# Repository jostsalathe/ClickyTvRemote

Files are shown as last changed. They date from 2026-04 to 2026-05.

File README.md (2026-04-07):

# ClickyTvRemote
A custom IR TV remote with mechanical keyboard switches

The project started because we have no remote any more for our Philips 32PFL5403D/12 TV.

IR codes for this Model can be found in the [IRDB on Github](https://github.com/probonopd/irdb/blob/master/codes/Philips/Unknown_32PFL5403D/0%2C-1.csv).

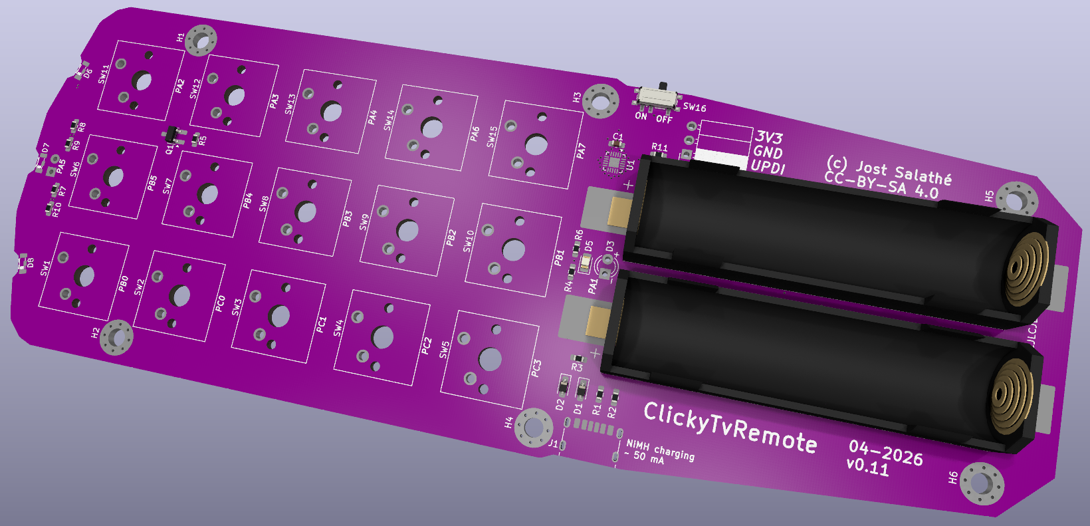
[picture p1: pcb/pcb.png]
PCB image


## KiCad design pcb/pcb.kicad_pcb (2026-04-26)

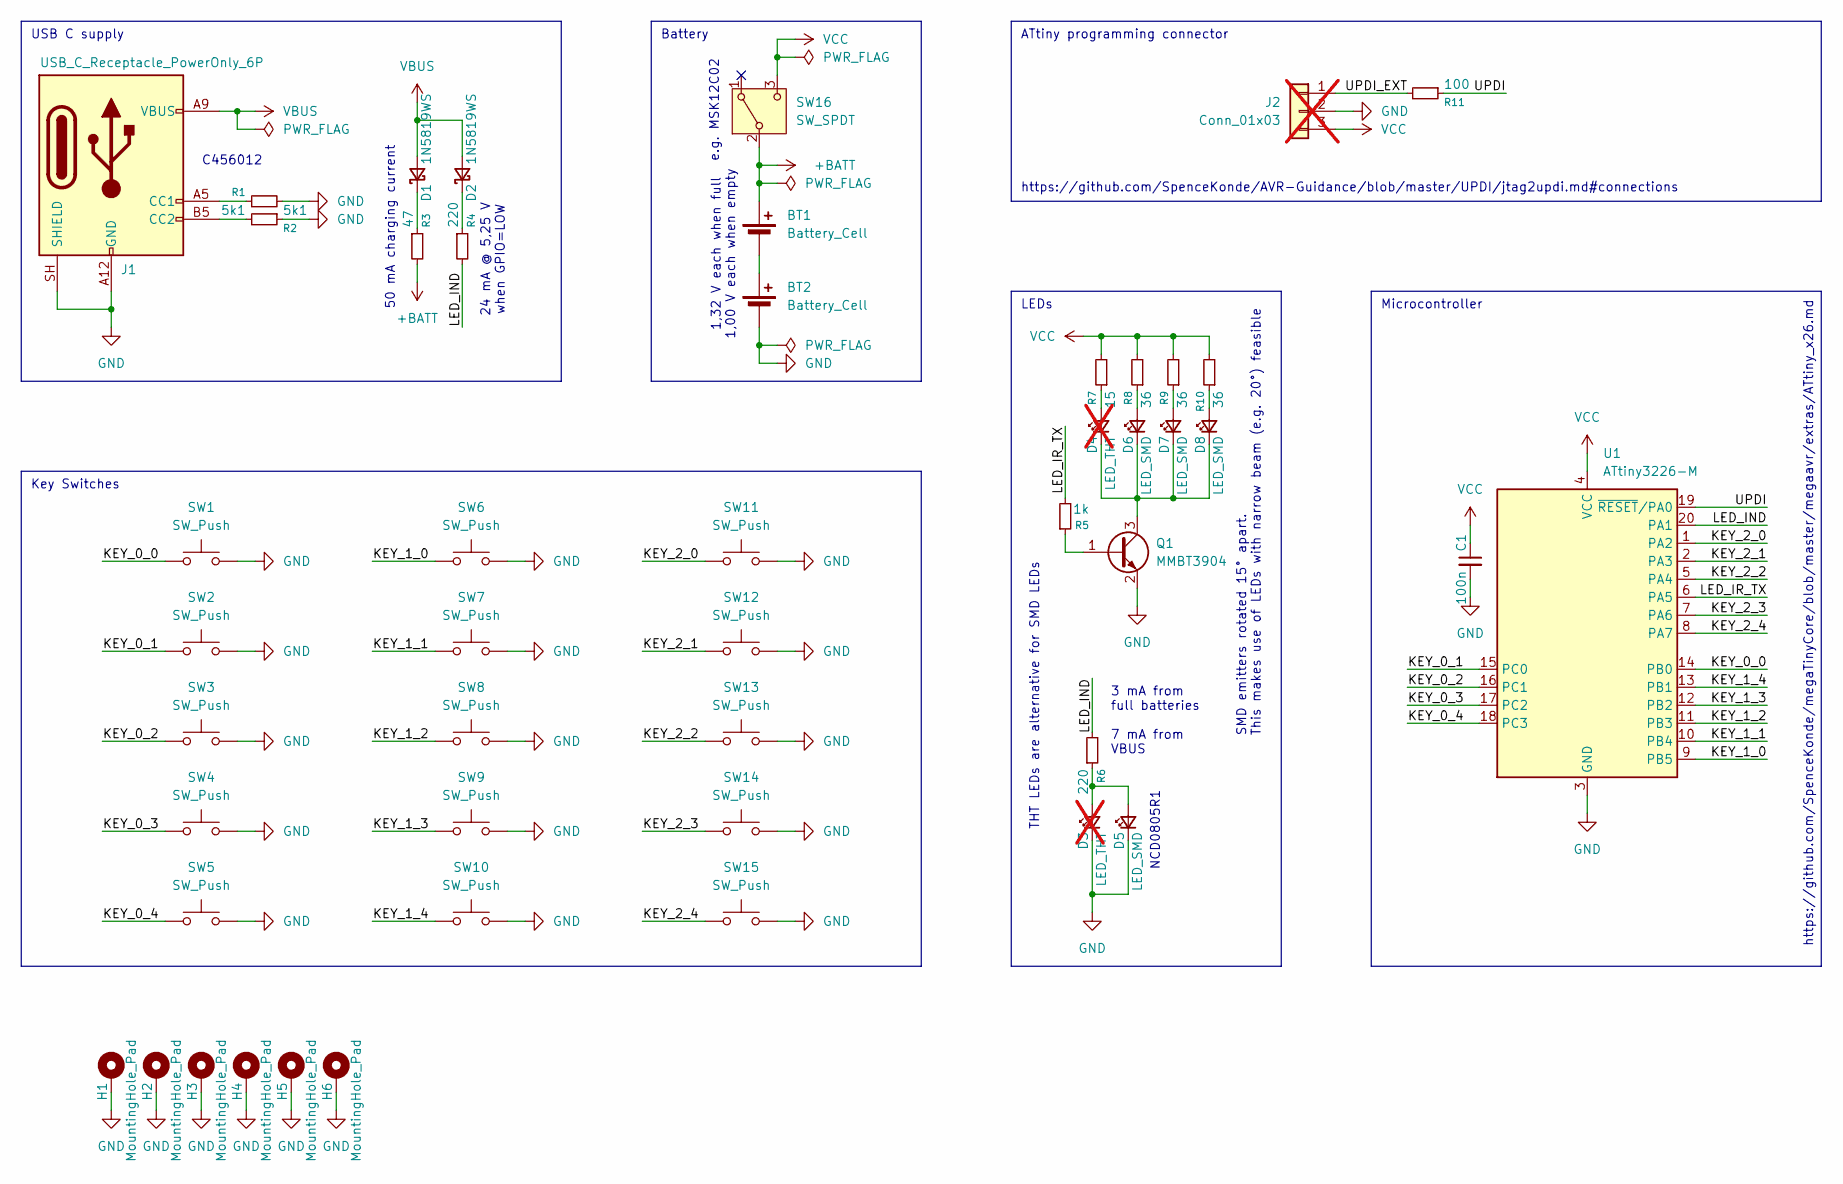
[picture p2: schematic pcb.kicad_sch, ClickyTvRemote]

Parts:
BT1, BT2: Battery_Cell; MYOUNG_AA_BH-AA-B5BA026; LCSC C20606794
C1: 100n; C_0603_1608Metric_Pad1.08x0.95mm_HandSolder; LCSC C14663
D1, D2: 1N5819WS; D_SOD-323_HandSoldering; LCSC C191023
D3: LED_THT; LED_D3.0mm; not fitted
D4: LED_THT; LED_D3.0mm_Horizontal_O1.27mm_Z2.0mm_IRBlack; not fitted
D5: LED_SMD; LED_0805_2012Metric_Pad1.15x1.40mm_HandSolder; LCSC C84256
D6, D7, D8: LED_SMD; IR12-21CTR8; LCSC C53672
H1, H2, H3, H4, H5, H6: MountingHole_Pad; MountingHole_3.2mm_M3_Pad_Via
J1: USB_C_Receptacle_PowerOnly_6P; USB_C_Receptacle_HRO_TYPE-C-31-M-17; LCSC C456012
J2: Conn_01x03; PinSocket_1x03_P2.54mm_Horizontal; not fitted
Q1: MMBT3904; SOT-23_Handsoldering; LCSC C20526
R1, R2: 5k1; R_0603_1608Metric_Pad0.98x0.95mm_HandSolder; LCSC C23186
R3: 47; R_0603_1608Metric_Pad0.98x0.95mm_HandSolder; LCSC C23182
R4, R6: 220; R_0603_1608Metric_Pad0.98x0.95mm_HandSolder; LCSC C22962
R5: 1k; R_0603_1608Metric_Pad0.98x0.95mm_HandSolder; LCSC C21190
R7: 15; R_0603_1608Metric_Pad0.98x0.95mm_HandSolder; LCSC C22810
R8, R9, R10: 36; R_0603_1608Metric_Pad0.98x0.95mm_HandSolder; LCSC C23148
R11: 100; R_0603_1608Metric_Pad0.98x0.95mm_HandSolder; LCSC C22775
SW1, SW2, SW3, SW4, SW5, SW6, SW7, SW8, SW9, SW10, SW11, SW12, SW13, SW14, SW15: SW_Push; SW_Cherry_MX_1.00u_PCB
SW16: SW_SPDT; SW_SPDT_PCM12; LCSC C431540
U1: ATtiny3226-M; VQFN-20-1EP_3x3mm_P0.4mm_EP1.7x1.7mm; LCSC C5227682

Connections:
+BATT: BT1.1 (+), R3.2, SW16.2 (B)
/KEY_0_0: SW1.1, U1.14 (PB0)
/KEY_0_1: SW2.1, U1.15 (PC0)
/KEY_0_2: SW3.1, U1.16 (PC1)
/KEY_0_3: SW4.1, U1.17 (PC2)
/KEY_0_4: SW5.1, U1.18 (PC3)
/KEY_1_0: SW6.1, U1.9 (PB5)
/KEY_1_1: SW7.1, U1.10 (PB4)
/KEY_1_2: SW8.1, U1.11 (PB3)
/KEY_1_3: SW9.1, U1.12 (PB2)
/KEY_1_4: SW10.1, U1.13 (PB1)
/KEY_2_0: SW11.1, U1.1 (PA2)
/KEY_2_1: SW12.1, U1.2 (PA3)
/KEY_2_2: SW13.1, U1.5 (PA4)
/KEY_2_3: SW14.1, U1.7 (PA6)
/KEY_2_4: SW15.1, U1.8 (PA7)
/LED_IND: R4.2, R6.2, U1.20 (PA1)
/LED_IR_TX: R5.2, U1.6 (PA5)
/UPDI: R11.1, U1.19 (~RESET/PA0)
/UPDI_EXT: J2.1, R11.2
GND: BT2.2 (-), C1.2, D3.1 (K), D5.1 (K), H1.1 (1_1), H2.1 (1_1), H3.1 (1_1), H4.1 (1_1), H5.1 (1_1), H6.1 (1_1), J1.A12 (GND), J1.B12 (GND), J1.SH (SHIELD), J2.2, Q1.2 (E), R1.2, R2.1, SW1.2, SW2.2, SW3.2, SW4.2, SW5.2, SW6.2, SW7.2, SW8.2, SW9.2, SW10.2, SW11.2, SW12.2, SW13.2, SW14.2, SW15.2, U1.3 (GND), U1.21 (GND)
unnamed: BT1.2 (-), BT2.1 (+)
unnamed: D1.1 (K), R3.1
unnamed: D2.1 (K), R4.1
unnamed: D3.2 (A), D5.2 (A), R6.1
unnamed: D4.2 (A), R7.1
unnamed: D4.1 (K), D6.1 (K), D7.1 (K), D8.1 (K), Q1.3 (C)
unnamed: D6.2 (A), R8.1
unnamed: D7.2 (A), R9.1
unnamed: D8.2 (A), R10.1
unnamed: J1.A5 (CC1), R1.1
unnamed: J1.B5 (CC2), R2.2
unnamed: Q1.1 (B), R5.1
VBUS: D1.2 (A), D2.2 (A), J1.A9 (VBUS), J1.B9 (VBUS)
VCC: C1.1, J2.3, R7.2, R8.2, R9.2, R10.2, SW16.3 (C), U1.4 (VCC)

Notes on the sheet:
Microcontroller
THT LEDs are alternative for SMD LEDs
Key Switches
https://github.com/SpenceKonde/megaTinyCore/blob/master/megaavr/extras/ATtiny_x26.md
https://github.com/SpenceKonde/AVR-Guidance/blob/master/UPDI/jtag2updi.md#connections
24 mA @ 5,25 V when GPIO=LOW
3 mA from full batteries 7 mA from VBUS
1,32 V each when full 1,00 V each when empty
e.g. MSK12C02
C456012
NCD0805R1
Battery
LEDs
USB C supply
ATtiny programming connector
SMD emitters rotated 15° apart. This makes use of LEDs with narrow beam (e.g. 20°) feasible
50 mA charging current

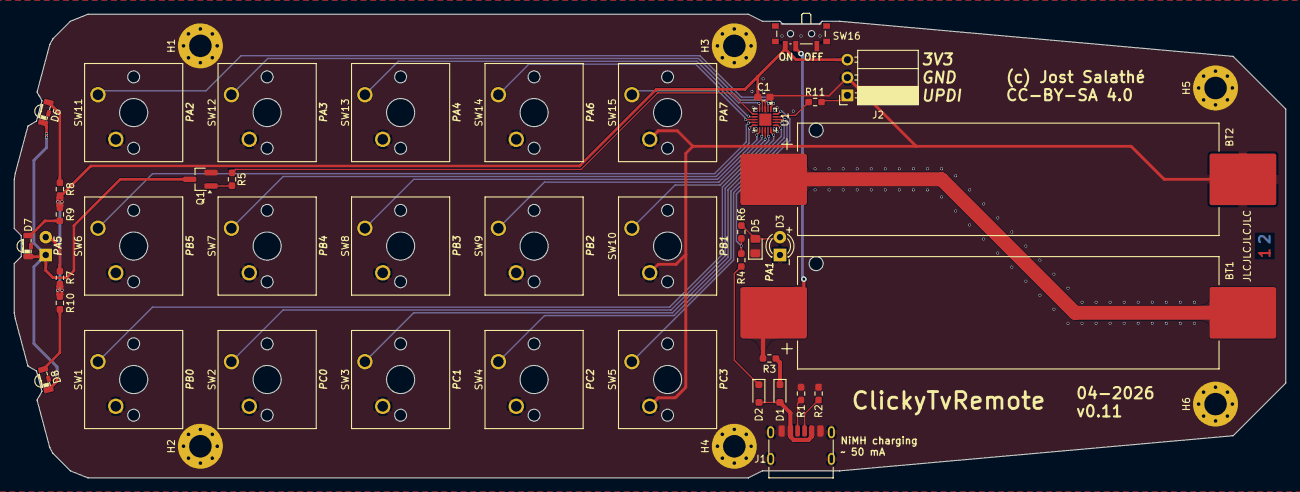
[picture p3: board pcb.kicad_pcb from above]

Board: 2 copper layers, 181.0 x 66.0 mm, 48 parts (1 on the bottom side), 35 nets.

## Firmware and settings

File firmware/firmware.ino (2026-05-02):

/************************
 *
 * This is builtfor the ClickyRemote running on an ATtiny3226.
 * You need the TinyMegaCore board package and the IRremote library.
 * Set Tools -> Clock -> 8 MHz internal
 *
 ************************/

#include <avr/sleep.h>


#define IR_SEND_PIN PIN_PA5

#define DISABLE_CODE_FOR_RECEIVER // Disables static receiver code like receive timer ISR handler and static IRReceiver and irparams data. Saves 450 bytes program memory and 269 bytes RAM if receiving functions are not required.
#define IR_USE_AVR_TIMER_A        // Fix because ATtiny3226 is not explicitly supported by the IRremote library, yet...

#undef LED_BUILTIN                // No LED defined in megaTinyCore
#define LED_BUILTIN PIN_PA1
//#define NO_LED_FEEDBACK_CODE      // Saves 216 bytes program memory

#ifdef NO_LED_FEEDBACK_CODE
#define ON_PRINT(A) A
#else
#define ON_PRINT(A)
#endif

#include <IRremote.hpp>


/* function prototypes */

void setPinModes(bool prepareSleep);
void powerDown();
void reportBattery(bool print);


/* structure definitions */

struct Command {
  int keyPin;
  uint8_t rc6Address;
  uint8_t rc6Command;
  const char* name;
};

struct VoltageToSoc {
    uint16_t voltageMv;
    uint8_t soc; // in %
};


/* static variable definitions */

static constexpr int TIME_DEBOUNCE_MS = 10;
static constexpr int TIME_SINGLE_PRESS_MS = 500;
static constexpr int TIME_REPEAT_PRESS_MS = 100;
static constexpr int TIME_BEFORE_POWERDOWN_MS = 2000;

// codes for Philips 32PFL5403D according to IRDB
// https://github.com/probonopd/irdb/blob/master/codes/Philips/Unknown_32PFL5403D/0%2C-1.csv
static constexpr Command commands[] = {
  {PIN_PB0, 0xff, 0xff, "KEY_BAT"},        // KEY_0_0
  {PIN_PB5, 0, 12, "KEY_PWR"},             // KEY_1_0
  {PIN_PA2, 0, 12, "KEY_PWR"},             // KEY_2_0
  {PIN_PC0, 0, 32, "KEY_CHANNELUP"},       // KEY_0_1
  {PIN_PB4, 0, 16, "KEY_VOLUMEUP"},        // KEY_1_1
  {PIN_PA3, 0, 245, "KEY_Picture_Format"}, // KEY_2_1
  {PIN_PC1, 0, 33, "KEY_CHANNELDOWN"},     // KEY_0_2
  {PIN_PB3, 0, 17, "KEY_VOLUMEDOWN"},      // KEY_1_2
  {PIN_PA4, 0, 13, "KEY_MUTE"},            // KEY_2_2
  {PIN_PC2, 0, 84, "KEY_MENU"},            // KEY_0_3
  {PIN_PB2, 0, 88, "KEY_UP"},              // KEY_1_3
  {PIN_PA6, 0, 92, "KEY_OK"},              // KEY_2_3
  {PIN_PC3, 0, 90, "KEY_LEFT"},            // KEY_0_4
  {PIN_PB1, 0, 89, "KEY_DOWN"},            // KEY_1_4
  {PIN_PA7, 0, 91, "KEY_RIGHT"},           // KEY_2_4
};

// millivolt -> state of charge look up table for two NiMH cells
static constexpr VoltageToSoc voltSocLUT[] = {
    {2900, 100},
    {2760, 95},
    {2680, 90},

    // Plateau (wichtigster Bereich!)
    {2600, 80},
    {2570, 70},
    {2540, 60},
    {2520, 50},
    {2500, 40},
    {2480, 30},

    // Entladungsknick
    {2440, 20},
    {2400, 10},
    {2360, 5},
    {2300, 2},
    {2200, 0}
};

/* global variables */

volatile uint32_t timeForPowerDownMs = 0;


void setup() {
  // put your setup code here, to run once:

  // upon waking if you plan to use the ADC
  ADC0.CTRLA |= ADC_ENABLE_bm;
  analogReference(INTERNAL1V024); // set reference to the desired voltage, and set that as the ADC reference.
  uint16_t reading = analogRead(ADC_VDDDIV10); //first reading might be inaccturate
  (void) reading; // to suppress unused variable warning

  // after wakeup, disable interrupts and enable Pullups for all buttons
  setPinModes(false);

  ON_PRINT(Serial.pins(PIN_PA1, PIN_PA2));
  ON_PRINT(Serial.begin(230400, SERIAL_TX_ONLY));

  ON_PRINT(Serial.println());
  ON_PRINT(Serial.println());
  ON_PRINT(Serial.println(F("START " __FILE__ "\r\n from " __DATE__ " " __TIME__ "\r\n using library version " VERSION_IRREMOTE)));
  ON_PRINT(Serial.print(F("Send IR signals at pin ")));
  ON_PRINT(Serial.println(IR_SEND_PIN));
  ON_PRINT(Serial.println());
  timeForPowerDownMs = millis() + TIME_BEFORE_POWERDOWN_MS;
}

void loop() {
  // check if inactive for long enough to power down
  if (millis() > timeForPowerDownMs) {
    powerDown();
  }

  // read buttons and find out what woke up the controller
  const Command *triggeredCmd = nullptr;
  for (const Command &cmd : commands) {
    if (!digitalRead(cmd.keyPin)) {
      // this commands key was pressed
      triggeredCmd = &cmd;
      break;
    }
  }

  // execute triggered command
  if (triggeredCmd != nullptr) {
    auto timeNextSendMs = millis();
    int sendCount = 0;

    ON_PRINT(Serial.print(millis()));
    ON_PRINT(Serial.print(" ms - pressed "));
    ON_PRINT(Serial.print(triggeredCmd->name));

    // debounce
    while (millis() - timeNextSendMs < TIME_DEBOUNCE_MS) {
      if (digitalRead(triggeredCmd->keyPin)) {
        ON_PRINT(Serial.println(" - debounce abort"));
        return;
      }
    }

    // still pressed - commence action
    if (triggeredCmd->rc6Address == 0xff && triggeredCmd->rc6Command == 0xff) {
      // handle battery readout
      reportBattery(true);
      while (digitalRead(triggeredCmd->keyPin) == LOW) {
        reportBattery(false);
      }
      ON_PRINT(Serial.println());
      timeForPowerDownMs = millis() + TIME_BEFORE_POWERDOWN_MS;
      return;
    } else {
      // send command
      ON_PRINT(Serial.print(" - sending "));
      ON_PRINT(Serial.print(triggeredCmd->rc6Command));

      // send once
      IrSender.sendRC6(triggeredCmd->rc6Address, triggeredCmd->rc6Command, 0);
      ++sendCount;
      ON_PRINT(Serial.print("."));

      // wait for single send release
      timeNextSendMs += TIME_SINGLE_PRESS_MS;
      while (millis() < timeNextSendMs) {
        if (digitalRead(triggeredCmd->keyPin)) {
          ON_PRINT(Serial.println(" 1 time"));
          timeForPowerDownMs = millis() + TIME_BEFORE_POWERDOWN_MS;
          return;
        }
      }

      // enter repeat mode for as long as key continues to be pressed
      while (true) {
        IrSender.sendRC6(triggeredCmd->rc6Address, triggeredCmd->rc6Command, 0);
        ++sendCount;
        ON_PRINT(Serial.print("."));
        timeNextSendMs += TIME_REPEAT_PRESS_MS;
        while (millis() < timeNextSendMs) {
          if (digitalRead(triggeredCmd->keyPin)) {
            ON_PRINT(Serial.print(" "));
            ON_PRINT(Serial.print(sendCount));
            ON_PRINT(Serial.println(" times"));
            ON_PRINT(Serial.flush());
            timeForPowerDownMs = millis() + TIME_BEFORE_POWERDOWN_MS;
            return;
          }
        }
      }
    }
  }
}


void setPinModes(bool prepareSleep) {
  const uint8_t newPinMode = 0b1000 | (prepareSleep ? PORT_ISC_LEVEL_gc : PORT_ISC_INTDISABLE_gc);
  
  // enable pin change interrupt for all buttons
  pinMode(LED_BUILTIN, OUTPUT);
  digitalWrite(LED_BUILTIN, LOW);
  pinMode(IR_SEND_PIN, OUTPUT);
  digitalWrite(IR_SEND_PIN, LOW);

  PORTA.PIN2CTRL = newPinMode;
  PORTA.PIN3CTRL = newPinMode;
  PORTA.PIN4CTRL = newPinMode;
  PORTA.PIN6CTRL = newPinMode;
  PORTA.PIN7CTRL = newPinMode;
  PORTB.PIN0CTRL = newPinMode;
  PORTB.PIN1CTRL = newPinMode;
  PORTB.PIN2CTRL = newPinMode;
  PORTB.PIN3CTRL = newPinMode;
  PORTB.PIN4CTRL = newPinMode;
  PORTB.PIN5CTRL = newPinMode;
  PORTC.PIN0CTRL = newPinMode;
  PORTC.PIN1CTRL = newPinMode;
  PORTC.PIN2CTRL = newPinMode;
  PORTC.PIN3CTRL = newPinMode;
}

void powerDown() {
  // Before sleeping
  ON_PRINT(Serial.print(millis()));
  ON_PRINT(Serial.println(" ms - Entering deep sleep..."));
  ADC0.CTRLA &= ~ADC_ENABLE_bm; //Very important on the tinyAVR 2-series

  set_sleep_mode(SLEEP_MODE_PWR_DOWN);
  sleep_enable();

  // and clear interrupt flags
  PORTA.INTFLAGS = 0xff;
  PORTB.INTFLAGS = 0xff;
  PORTC.INTFLAGS = 0xff;

  // enable pin change interrupt for all buttons
  ON_PRINT(Serial.flush());
  ON_PRINT(Serial.end());
  setPinModes(true);

  sleep_cpu();
}

uint8_t voltageToSoc(uint16_t mv) {
    constexpr uint8_t n = sizeof(voltSocLUT) / sizeof(voltSocLUT[0]);

    for (int i = 0; i < n - 1; ++i) {
        const uint16_t mvHigh = voltSocLUT[i].voltageMv;
        const uint8_t socHigh = voltSocLUT[i].soc;
        const uint16_t mvLow = voltSocLUT[i+1].voltageMv;
        const uint8_t socLow = voltSocLUT[i+1].soc;

        if (mv <= mvHigh && mv >= mvLow) {
            const uint16_t dmv = mv - mvLow;
            const uint16_t ds = socHigh - socLow;

            // nur hier kurz 32-bit für Sicherheit
            int32_t interp = (int32_t)dmv * ds;

            return socLow + interp / (mvHigh - mvLow);
        }
    }

    return (mv > voltSocLUT[0].voltageMv) ? 100 : 0;
}

void dimLedBuiltinDelay(uint16_t ms, uint8_t brightness) {
  auto end = millis() + ms;
  while(millis() < end) {
    if ( ((micros() / 4) % 256) < brightness) {
      digitalWriteFast(LED_BUILTIN, HIGH);
    } else {
      digitalWriteFast(LED_BUILTIN, LOW);
    }
  }
}

void reportBattery(bool print) {
  uint16_t uBatMv = analogReadEnh(ADC_VDDDIV10, 14, 2) * 10 / 32; // read battery voltage
  uBatMv -= 20; // offset calibration
  uint8_t soc = voltageToSoc(uBatMv);// calculate battery level
  // report battery level
#ifdef NO_LED_FEEDBACK_CODE
  if (print) {
    ON_PRINT(Serial.print(" - UBat = "));
    ON_PRINT(Serial.print(uBatMv));
    ON_PRINT(Serial.print(" mV ("));
    ON_PRINT(Serial.print(soc));
    ON_PRINT(Serial.println(" %)"));
  }
#else
  // via blink code on LED_BUILTIN
  soc = (soc + 5) / 10; // for correct roundling with step size of 10%
  for (int i = 0; i < 10; ++i) {
    bool on = soc > i;
    dimLedBuiltinDelay(on ? 200 : 10, 32);
    digitalWrite(LED_BUILTIN, LOW);
    delay(on ? 300 : 490);
  }
#endif
}

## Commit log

2026-03-29 added the ATtiny3226, one switch and signal labels for all wanted switches
    [pcb.kicad_pcb, pcb.kicad_sch]
2026-03-29 migrated pcb design to KiCAD 10.0 and added some components
    [pcb.kicad_sch]
2026-03-29 added first firmware draft (for now just trying out stuff on an Arduino Nano)
2026-03-29 added indicator LED and correct labels for all signals
    [pcb.kicad_sch]
2026-03-29 fixed volume button direction
    [firmware.ino]
2026-04-03 added Function struct and improved press timing and repeat handling The new Function struct helps to better organize function definitions and key pin association as well as reduce code duplication. T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
2026-04-03 renamed functions to commands added command definitions as comments in preparation for the ATtiny pcb
2026-04-03 completed first draft of schematics
    [pcb.kicad_sch]
2026-04-04 fixed battery clip 3D model scale
2026-04-04 Added mounting holes and started work on layout
    [pcb.kicad_pcb, pcb.kicad_sch]
2026-04-04 Completed routing of all signals and rearranged key signals for better routing
    [pcb.kicad_pcb, pcb.kicad_sch]
2026-04-04 changed THT IR LED footprint in schematics for one that has less body offset
    [pcb.kicad_sch]
2026-04-04 completed layout with info texts and everything
    [pcb.kicad_pcb]
2026-04-04 Added LCSC part numbers
    [pcb.kicad_pcb, pcb.kicad_sch]
2026-04-04 fixed DRC errors and warnings
    [pcb.kicad_pcb]
2026-04-04 added JLCPCB order number place holder
    [pcb.kicad_pcb]
2026-04-04 resized JLCPCB order number place holder
    [pcb.kicad_pcb]
2026-04-04 made vias larger to fall into cheaper manufacturing constraints
    [pcb.kicad_pcb]
2026-04-07 fixed SMD indicator LED footprint changed from 1206 to 0805 size, because they are cheaper at JLCPCB
    [pcb.kicad_pcb, pcb.kicad_sch]
2026-04-07 added rendered image of PCB v0.11
2026-04-25 changed over from Arduino Nano to ATtiny3226 pinout
2026-04-26 add thermal reliefs to BT2 Pad 2 (connected to GND plane)
    [pcb.kicad_pcb]
2026-05-01 prepared some code for batteryreporting
2026-05-01 completed power down and wakeup implementation
2026-05-01 completed battery voltage reading and serial printout
2026-05-02 deepSleep() becomes powerDown()
2026-05-02 added SOC reporting via blinking indicator LED
2026-05-02 added back missing powerDown() call that was erroneously removed some commits ago
    [firmware.ino]
2026-05-02 delayed powerDown to 2 seconds after last activity so that rapid successive keypresses are actually interpreted by the receiving device

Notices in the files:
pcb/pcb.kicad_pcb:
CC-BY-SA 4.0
